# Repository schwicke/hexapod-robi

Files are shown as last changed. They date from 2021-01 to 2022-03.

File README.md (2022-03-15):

# A hexapod robot
The aim of this little project is the creation of a fully self-designed and 3d printed hexapod robot. Basic features:

* 6 legs with 3 Dynamixel motors each
* Controls and feedback through Raspberry-Pi
* Plastic parts self-designed and 3d printed
* Modular design
* Battery or cable driven
* Sensors:
    * pressure sensors in the feeds
    * ultrasonic sensors
    * gyroscopic sensor

The longer term goal is to equip this robot with various additional sensors, giving feedback about the environment and orientation of the robot.

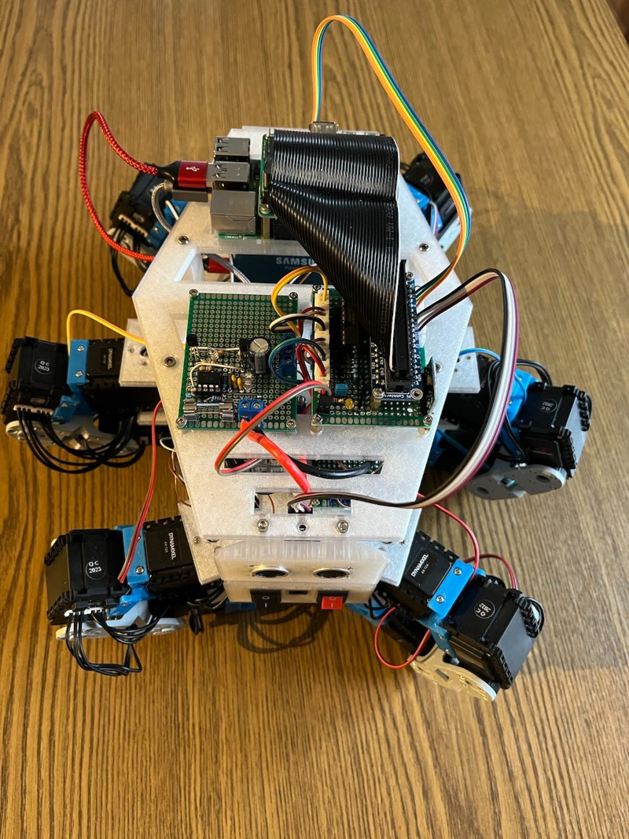
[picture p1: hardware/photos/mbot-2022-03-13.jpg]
Latest robot


## Hardware
A description of the hardware can be found in in the [hardware folder](hardware/README.md).

## Software
The (still PoC level) software is available [here](software/README.md).

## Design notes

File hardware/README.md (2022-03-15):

# Hardware parts
## 3d-printed parts
OpenScad has been used to design the 3d printed parts for this robot. Source files are in the scad folder. These may change at any time and might not work as expected.

The stl folder contains the latest released versions of the plastic parts in STL format, which can be used with your favorite slicer. The intention is to keep them more stable than the source OpenScad files above.

## Required parts list for the robot
Plastic parts: Most up-to-date are the source files for OpenSCAD.

### Legs
* ./legs/joint_30_degrees.scad
* ./legs/leg_connector_boxes_side.scad
* ./legs/sensorunit_bottom.scad
* ./legs/sensorunit_middle.scad
* ./legs/sensorunit_top.scad
* ./legs/leg_connector_boxes.scad

### Body
The body part has 3 different layers, which are:

* ./body/bodybottom.scad
* ./body/bodymiddle.scad
* ./body/bodytop.scad

These are connected using the mount parts

* ./body/mount2.scad
* ./body/mount.scad

The lowest layer hosts the connectors for the motors. For each motor connector, an appropriate connector box is needed:
* ./body/connector_boxes.scad

Finally the body sides are moduler. Currently existing are:
* ./body/side_sensor.scad for the ultrasonic sensors
* ./body/side_power.scad  contains holes for switches
* ./body/side_battery.scad contains holes for the battery connectors

## Electronics:

* 18 Dynamixel AX-12A kits (we need the screws and plastic parts available in these kits as well)
* 1x Raspberry-pi 4b
* 1x Strompi board (Joy-IT)
* 1x Robotis U2D2 board and power distributior
* 2x HC-SR04 Ultrosonic sensors
* 1x MPU6050 sensor
* ADC0838 IC
* LiPo battery, cables and connectors and suitable charger
* 512GB external SSD disk
* 1x voltage converter 12V -> 5V 3A, see circuit diagram
* 1x voltage control board, see circuit diagram below
* 1x ADC board, see circuit diagram below
* 6x RP-C10-ST pressure sensores for the legs

Other parts and materials

* 15x Molex P3 plugs
* 10x 10cm p3 cables from Robotis
* perfboard, cutable into pieces
* 2 small USB cables
* cables, crimp tool, and 4 and 2 pin plugs are needed to connect the sensors

Screws: hexagonal heads, various lengths. These sizes have been used:

* M1.4 (10mm) screws and nuts, at least 8 to fix the HC-SR04 sensors
* M2 (10mm) screws and M2 nuts to mount the legs
* M2.5 (8mm) screws, nuts and washers
* M3 screws and washers

### Motor connectors
Connecting the motors is a bit tricky due to the length of the available cables.
Therefore, in front of roughly each leg there we added additional P3 plugs which help reducing the cable lengths.
The bottom part of the robot has holes forseen for these hubs. To create them, the Molex P3 plugs are soldered on small bits of a PCB perfboard, 3 in pairs of 3 and 2 in pairs of 2 are needed. The pins are to be paired up, like this:

3x motor connector

This picture shows the parts needed to create those boxes:

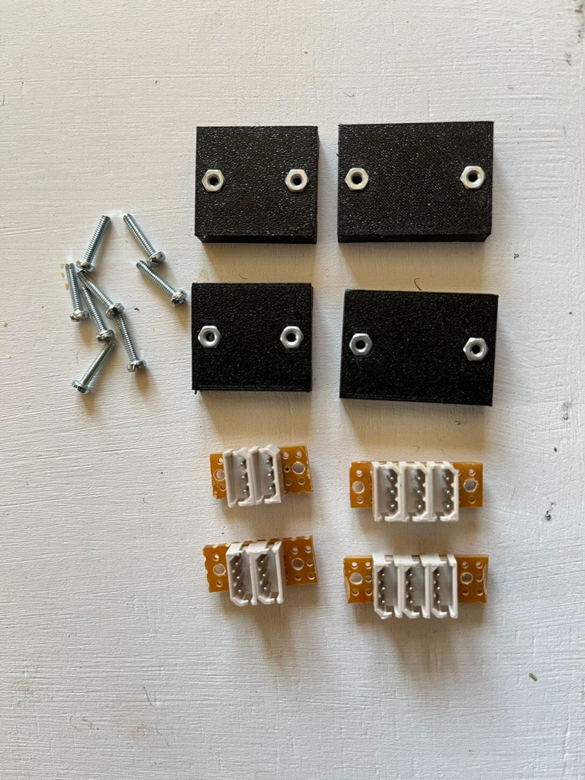
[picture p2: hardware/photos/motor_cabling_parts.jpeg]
Connector parts


The plugs are then inserted into the holes into the bottom part of the robot from below, and fixed with screws with the help of the printed connector boxes. A power distirbution hub seen from below the robot looks like this:
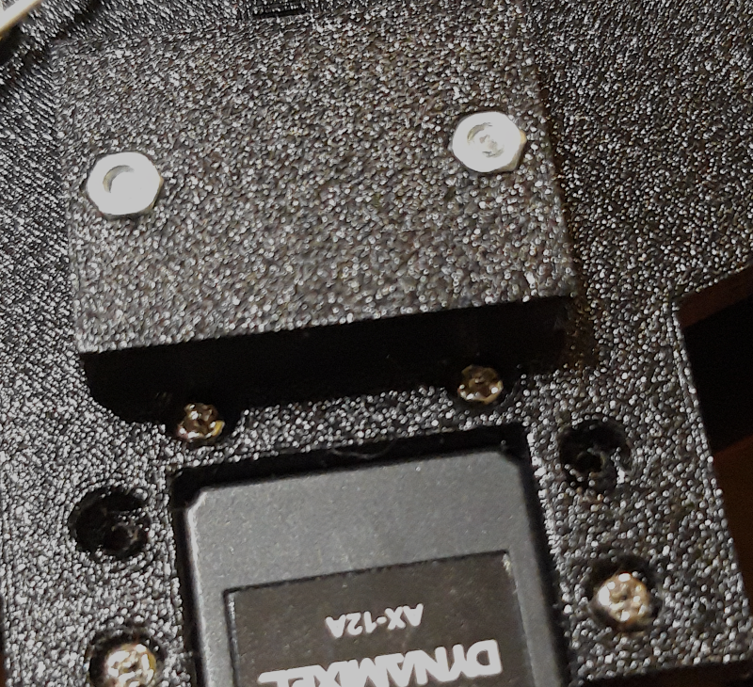
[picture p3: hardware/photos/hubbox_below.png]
Power hub from below


Cabling is done as in the following figure. The still empty plugs are used to connect the legs.

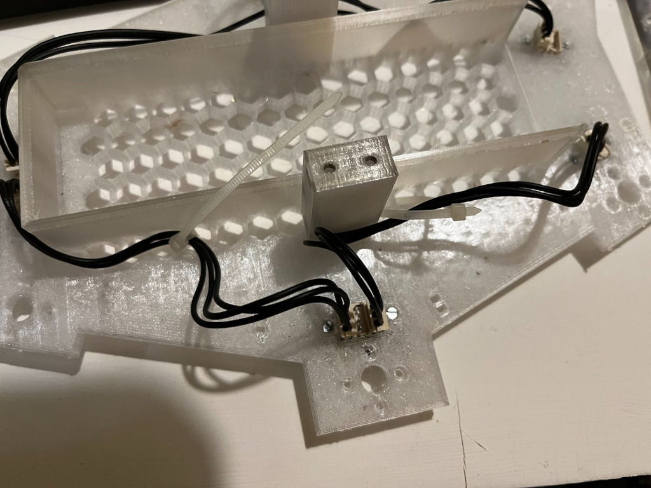
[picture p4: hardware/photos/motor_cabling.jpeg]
Motor cabling


## Voltage converter
A voltage converter is used to provide the required 5V power used by the Raspberry-Pi. The 5V output current is provided via a USB plug, and a short USB 2 to USBC cable is used to connect the two.

Circuits used

The converter is used as power supply for the sensors mainly, to offload the StromPi. As it may not be strictly needed it is possible that it will be dropped in the future.

For the voltage converter is built on a PCB perfboard with dimensions 40x60mm. The regulator IC needs an sufficiently sized heat sink.Using a voltage converter has the advantage that a single power supply of 12V can be used to power the hole robot. In a later version, this may be replaced by a 11.2V Lithium Polymere battery.

Here's a close-up image of how it looks like in reality:
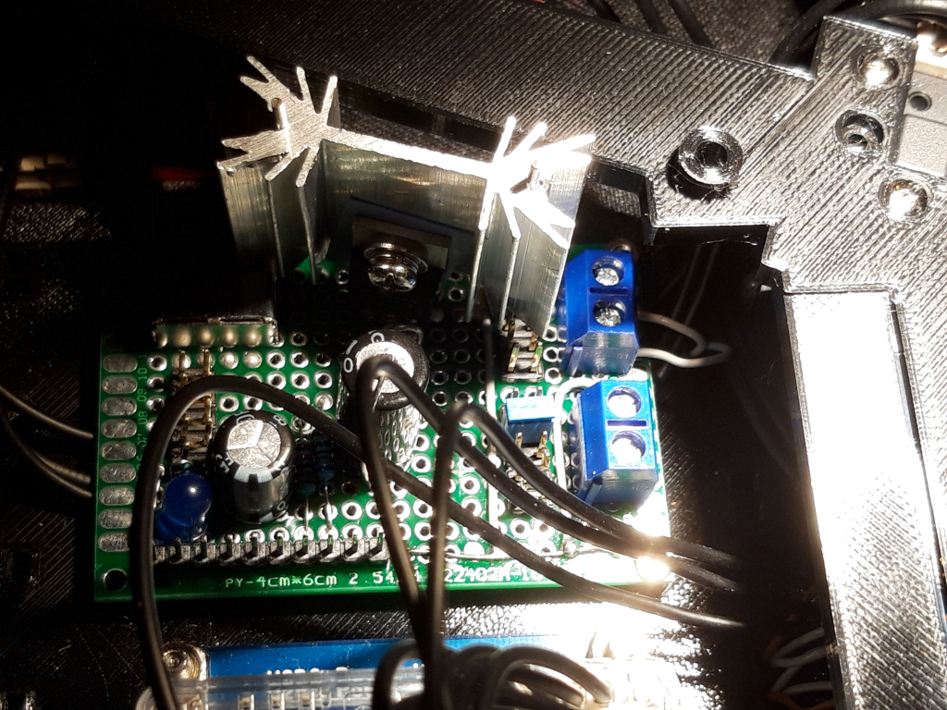
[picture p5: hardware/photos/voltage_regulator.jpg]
Power converter with heat sink


## Voltage controller
The voltage controller is needed to have some control over the status of the battery. It has 2 LEDs, and if the voltage drops too low, a red light will indicate that it is time to recharge the battery.

Circuits used

## ADC board
The ADC board uses an ADC0838 chip to digitize the signals from the pressure sensors in the feets of the robot.

Circuits used

## Layers

### Lowest layer
The first layer takes the motor cabling, as described above, and the battery. The battery should be fixed so that it cannot move or slip out of the robot. A piece of hook-and-loop tape can be used to accomplish this.

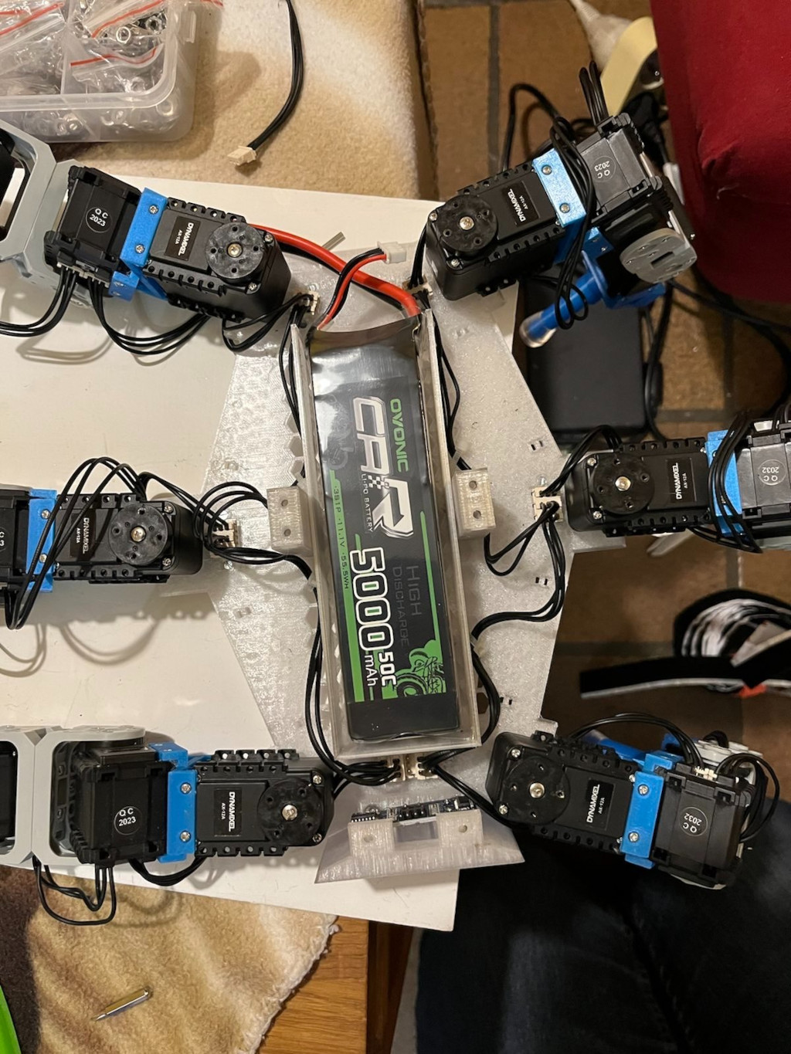
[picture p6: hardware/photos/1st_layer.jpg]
First layer


### Second layer
The second layer takes the SSD disk for the Raspberry-pi, the U2D2 board and optionally the 5V power converter.

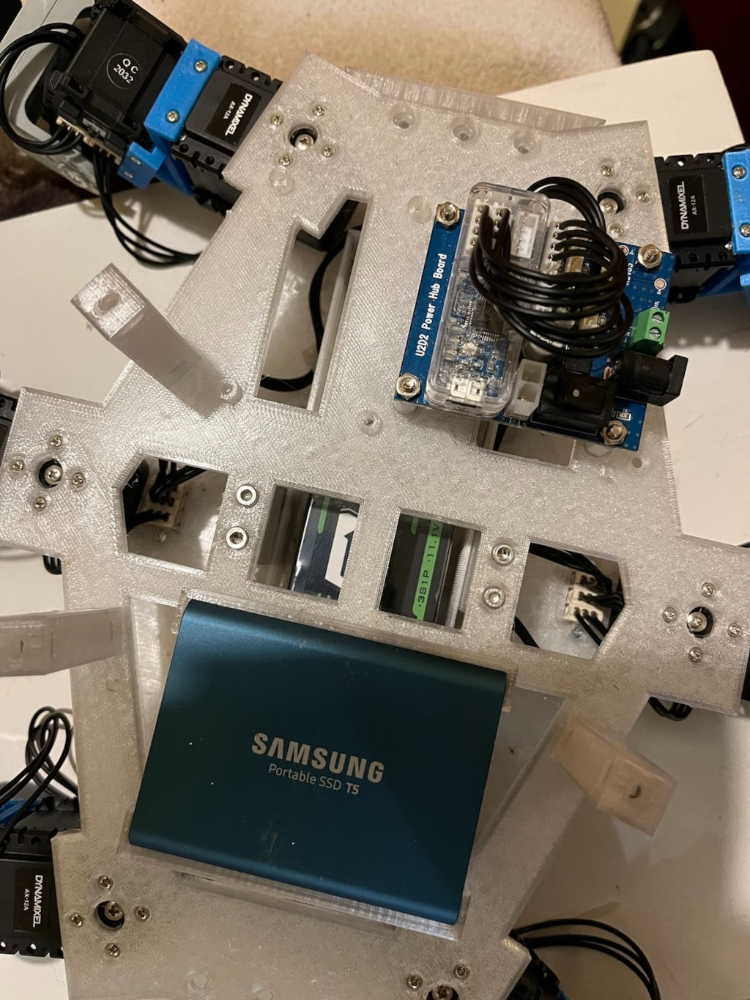
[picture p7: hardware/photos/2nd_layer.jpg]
Second layer


### Top layer
The top layer takes the electronics for the sensors, the Raspberry-Pi, and the power control board.

Third layer

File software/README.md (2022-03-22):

# Software
The software found in this repository is at a PoC level.
## Sensors
This directory contains a library and some tests to read out the robots sensors

## Python
In this folder, you can find some basic Python scripts for motor control
### scan.py
This tool simply scans the bus and returns the ids of the motors it found. There should be 3x6 so 18 of them.
### zero_position.py
This tool simply sets all motors to their zero position. In effect, the robot will stand up.
### walk.py
The walk.py script is a bit more complex. It implements some logic which allows the robot to move a few steps forward and backward.

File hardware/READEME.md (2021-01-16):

# Hardware bits
## 3d-printed parts
OpenScad has been used to design the 3d printed parts for this robot. Source files are in the scad folder. These may change at any time and might not work as expected.

The stl folder contains the latest released versions of the plastic parts in STL format, which can be used with your favorite slicer. The intention is to keep them more stable than the source OpenScad files above.

## Required parts list
Plastic parts:

* 6 legs (6x leg.stl)
* 1x bodybottom.stl
* 1x bodytop.stl
* 5x connector_boxes.stl
* 1x side_buttons.stl
* 1x side_power.stl

Other parts and materials
* 18 Dynamixel AX-12A kits (we need the screws and plastic parts available in these kits as well)
* 1x Robotis U2D2 board
* 1x Raspberry-Pi 4 with 16GB or 32GB SSD card
* 13x Molex P3 plugs
* 10x 10cm p3 cables from Robotis
* perfboard, cutable into pieces

Screws:
* M2 (10mm) screws and M2 nuts to mount the legs
* M2.5 (8mm) screws, nuts and washers
* M3 screws and washers

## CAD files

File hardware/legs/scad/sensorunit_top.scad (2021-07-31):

raster=2.54;
dist = 4.5*raster;

module screwhole_mX(d, height, fact){
   headlength = 0.6*d/2+0.1;
   translate([0,2,0]){
     rotate([90, 0, 0]){
       translate([0, 0, headlength/2]){
         translate([0, 0, height/2])
         cylinder(h=height, r=d/2+0.1, center=true, $fn=50);
         cylinder(h=10*fact*headlength, r=d+0.1, center=true, $fn=50);
       }
     }
   }
}

module nuthole_mX(d){
   s = (d==2) ? 4: (d==2.5)? 5: (d==3) ? 5.5: 0.0;
   if (s==0){
     echo ("Nut size not supported");
   }
   echo(s);
   e = s/sin(60.0);
   height = 40;
   headlength = 0.6*d/2+0.1;
   translate([0, 0, -5*headlength]){
     translate([0, 0, height/2])cylinder(h=height, r=d/2+0.1, center=true, $fn=50);
     cylinder(h=10*headlength, d=e+0.1, center=true, $fn=6);
   }
}

module baseelement(){
     difference(){
       union(){
         difference(){
         translate([0, 0, -4])cube([38, 25, 9], center=true);
         cube([32+0.2, 50, 9], center=true);
         };
       }
       translate([-19, -8, -2])rotate([0,0,90])screwhole_mX(2, 10, 1.0);
       translate([-19,  8, -2])rotate([0,0,90])screwhole_mX(2, 10, 1.0);
       translate([19, -8, -2])rotate([0,0,-90])screwhole_mX(2, 10, 1.0);
       translate([19,  8, -2])rotate([0,0,-90])screwhole_mX(2, 10, 1.0);
  }
}
z=50;
rad=6;
fn=150;
module leg(){
     cylinder(h=z, r=rad, center=false, $fn=fn);
     sphere(r=rad, $fn=fn);
}

//translate([0,0,-z])leg();
//cylinder(h=4, r=rad+1, center=true, $fn=fn);
//sphere(r=rad-2, $fn=fn);
thickness=3;


module tiltedthing(){
     union(){
          translate([0,-5,10])rotate([30,0,0])baseelement();
          translate([0,-0.9,-3])cube([38,22,3], center=true);
          translate([0,8.55,3])cube([38,3,12], center=true);
     }
}

difference(){
     tiltedthing();
     translate([-rad-5,0,2.5])rotate([90,0,0])screwhole_mX(2, 20, 2.0);
     translate([+rad+5,0,2.5])rotate([90,0,0])screwhole_mX(2, 20, 2.0);
     rotate([0,0,180])translate([0,0,-4.6])cylinder(r=rad+1.0,h=1.5,center=true,$fn=fn);
     rotate([0,0,180])translate([0,0,-3.8])cylinder(r=5.1,h=1.1, center=true, $fn=fn);
     rotate([0,0,180])translate([0,-rad,-4.1])cube([7,12,1.1], center=true);
     translate([-dist,8.5,2])rotate([-90,0,0])nuthole_mX(2);
     translate([+dist,8.5,2])rotate([-90,0,0])nuthole_mX(2);
     
}

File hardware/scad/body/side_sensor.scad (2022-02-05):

//
// This file is part of the hexapod-robi distribution (https://github.com/schwicke/hexapod-robi).
// Copyright (c) 2021 Ulrich Schwickerath
//
// This program is free software: you can redistribute it and/or modify
// it under the terms of the GNU General Public License as published by
// the Free Software Foundation, version 3.
//
// This program is distributed in the hope that it will be useful, but
// WITHOUT ANY WARRANTY; without even the implied warranty of
// MERCHANTABILITY or FITNESS FOR A PARTICULAR PURPOSE. See the GNU
// General Public License for more details.
//
// You should have received a copy of the GNU General Public License
// along with this program. If not, see <http://www.gnu.org/licenses/>.
//
// This is a little plastic bit which is intended to get the holes for the connectors
// at the right position. It's not part of the robot itself, but useful for building it.
//
include <../lib/globals.scad>
include <../lib/nuts_and_screws.scad>
include <../lib/sideparts.scad>

translate([0, 5, 0]){
  difference(){
    union(){
      translate([ screwdist_x/2, -1.5, -screwdist_y/2])rotate([90., 0., 0.])cylinder(h=3, d=4, center=true);
      translate([ screwdist_x/2, -1.5,  screwdist_y/2])rotate([90., 0., 0.])cylinder(h=3, d=4, center=true);
      translate([-screwdist_x/2, -1.5,  screwdist_y/2])rotate([90., 0., 0.])cylinder(h=3, d=4, center=true);
      translate([-screwdist_x/2, -1.5, -screwdist_y/2])rotate([90., 0., 0.])cylinder(h=3, d=4, center=true);
      difference(){
        sidepart();
        // HC SR04 sensor
        translate([ halfdist, 0, 0]) rotate([90, 0, 0]) cylinder(h=50, d=diameter, center=true);
        translate([-halfdist, 0, 0]) rotate([90, 0, 0]) cylinder(h=50, d=diameter, center=true);
        translate([0, -7, 0])cube([xsize+0.1, 12, ysize+0.2], center=true);
      }
    }
    translate([ screwdist_x/2, 0,  screwdist_y/2])rotate([-90., 0., 0.])my_screwhole_mX(1.6);
    translate([-screwdist_x/2, 0,  screwdist_y/2])rotate([-90., 0., 0.])my_screwhole_mX(1.6);
    translate([ screwdist_x/2, 0, -screwdist_y/2])rotate([-90., 0., 0.])my_screwhole_mX(1.6);
    translate([-screwdist_x/2, 0, -screwdist_y/2])rotate([-90., 0., 0.])my_screwhole_mX(1.6);
  }
}

translate([0, -5, hight/2-thickness_top/2]){
     difference(){
          rotate([0, 180, 0]) cube([45, 10, thickness_top], center=true);
          translate([ 16, 0, 0]) nuthole_mX(3);
          translate([-16, 0, 0]) nuthole_mX(3);
          translate([0, -0, 10])cube([15, 15, 30], center=true);
     }
}

translate([0, -5, -hight/2+thickness_bottom/2]){
     difference(){
          cube([45, 10, thickness_bottom], center=true);
          translate([  0, 0, 0])rotate([ 180.0 ,0.0 ,0.0 ])nuthole_mX(3);
          translate([ 16, 0, 0])rotate([ 180.0 ,0.0 ,0.0 ])nuthole_mX(3);
          translate([-16, 0, 0])rotate([ 180.0 ,0.0 ,0.0 ])nuthole_mX(3);
     }
}

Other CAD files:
hardware/scad/legs/joint_30_degrees.scad
hardware/scad/legs/leg_connector_boxes.scad
hardware/scad/body/bodybottom.scad
hardware/scad/body/bodymiddle.scad
hardware/scad/body/bodytop.scad
hardware/scad/body/connector_boxes.scad
hardware/scad/body/mount.scad
hardware/scad/body/mount2.scad
hardware/scad/body/side_battery.scad
hardware/scad/body/side_buttons.scad
hardware/scad/body/side_power.scad
hardware/scad/legs/leg_connector_boxes_side.scad
hardware/scad/legs/sensorunit_bottom.scad
hardware/scad/legs/sensorunit_middle.scad
hardware/scad/legs/sensorunit_top.scad

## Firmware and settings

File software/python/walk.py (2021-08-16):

#!/usr/bin/python3
#
# This file is part of the hexapod-robi distribution (https://github.com/schwicke/hexapod-robi).
# Copyright (c) 2021 Ulrich Schwickerath
#
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
""" PoC move primitives """
import sys
import time
#pylint: disable=no-member
from pypot import dynamixel

ALL_MOTORS = [1, 2, 3, 4, 5, 6, 7, 8, 9, 10, 11, 12, 13, 14, 15, 16, 17, 18]
PORT = dynamixel.find_port(ALL_MOTORS)
MOTOR = dynamixel.io.io.DxlIO(PORT, use_sync_read=False)

#print(m.get_angle_limit(ALL_MOTORS))
#print(m.get_control_mode(ALL_MOTORS))
#print(m.get_firmware(ALL_MOTORS))
#print(m.get_present_temperature(ALL_MOTORS))
print(MOTOR.get_present_speed(ALL_MOTORS))

LEG_MOTOR_SPEED = [50, 50, 50]
LEG_GROUPS = [[1, 3, 5], [2, 4, 6]]

# define positions
LEG_ZERO_POS = [0, 0, 0]
LEG_UP_POS = [None, 80, 80]
LEG_DOWN_POS = [None, 0, 0]
LEG_FORWARD_POS = [0, None, None]
LEG_BACKWARD_POS = [-30, None, None]
LEG_SIT_POS = [0, -55, 50]

def _define_motor_hash(legs, positions):
    """ legs: list of legs, position: list of 3 values  """
    res_hash = {}
    for leg in legs:
        for index in range(3):
            mindex = 3*(leg-1)+index + 1
            if positions[index] is not None:
                if mindex in [10, 13, 16] and index == 0:
                    res_hash[mindex] = -positions[index]
                else:
                    res_hash[mindex] = positions[index]
    return res_hash

LEG_GROUPS_SPEED = [_define_motor_hash(LEG_GROUPS[0], LEG_MOTOR_SPEED),
                    _define_motor_hash(LEG_GROUPS[1], LEG_MOTOR_SPEED)]
LEG_GROUPS_ZERO = [_define_motor_hash(LEG_GROUPS[0], LEG_ZERO_POS),
                   _define_motor_hash(LEG_GROUPS[1], LEG_ZERO_POS)]
LEG_GROUPS_UP = [_define_motor_hash(LEG_GROUPS[0], LEG_UP_POS),
                 _define_motor_hash(LEG_GROUPS[1], LEG_UP_POS)]
LEG_GROUPS_DOWN = [_define_motor_hash(LEG_GROUPS[0], LEG_DOWN_POS),
                   _define_motor_hash(LEG_GROUPS[1], LEG_DOWN_POS)]
LEG_GROUPS_FORWARD = [_define_motor_hash(LEG_GROUPS[0], LEG_FORWARD_POS),
                      _define_motor_hash(LEG_GROUPS[1], LEG_FORWARD_POS)]
LEG_GROUPS_BACKWARD = [_define_motor_hash(LEG_GROUPS[0], LEG_BACKWARD_POS),
                       _define_motor_hash(LEG_GROUPS[1], LEG_BACKWARD_POS)]
LEG_GROUPS_SIT = [_define_motor_hash(LEG_GROUPS[0], LEG_SIT_POS),
                  _define_motor_hash(LEG_GROUPS[1], LEG_SIT_POS)]

def zero():
    """ set all MOTORS to zero """
    MOTOR.set_goal_position(LEG_GROUPS_ZERO[0])
    MOTOR.set_goal_position(LEG_GROUPS_ZERO[1])

def set_speed(speed=50):
    """ set the motor speed for all groups """
    leg_groups_speed = [_define_motor_hash(LEG_GROUPS[0], [speed, speed, speed]),
                        _define_motor_hash(LEG_GROUPS[1], [speed, speed, speed])]
    MOTOR.set_moving_speed(leg_groups_speed[0])
    MOTOR.set_moving_speed(leg_groups_speed[1])

def walk_forward(steps, delay=0.5, speed=50):
    """ walk forward by the defined number of steps """
    set_speed(speed)
    zero()
    for i in range(steps):
        print("Step forward number: %d", i)
        for group in range(2):
            MOTOR.set_goal_position(LEG_GROUPS_UP[group])
            time.sleep(delay)
            MOTOR.set_goal_position(LEG_GROUPS_BACKWARD[1-group])
            time.sleep(delay)
            MOTOR.set_goal_position(LEG_GROUPS_FORWARD[group])
            time.sleep(delay)
            MOTOR.set_goal_position(LEG_GROUPS_DOWN[group])
            time.sleep(delay)

def walk_backward(steps, delay=0.5, speed=50):#
    """ walk backward by the defined number of steps """
    set_speed(speed)
    zero()
    for i in range(steps):
        print("Step backward number: %d", i)
        for group in range(2):
            MOTOR.set_goal_position(LEG_GROUPS_UP[group])
            time.sleep(delay)
            MOTOR.set_goal_position(LEG_GROUPS_FORWARD[1-group])
            time.sleep(delay)
            MOTOR.set_goal_position(LEG_GROUPS_BACKWARD[group])
            time.sleep(delay)
            MOTOR.set_goal_position(LEG_GROUPS_DOWN[group])
            time.sleep(delay)

def main():
    """ main entry point """
    set_speed(80)
    zero()
    steps = 5
    wait = 0.15
    speed = 130
    time.sleep(1)
    walk_backward(steps, wait, speed)
    #walk_forward(steps,  wait, speed)
    set_speed(30)
    MOTOR.set_goal_position(LEG_GROUPS_SIT[1])
    MOTOR.set_goal_position(LEG_GROUPS_SIT[0])
    #zero()

if __name__ == '__main__':
    sys.exit(main())

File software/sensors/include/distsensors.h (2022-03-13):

#ifndef HCSR04_H
#define HCSR04_H
#include "common.h"
/* define trigger and echo pins for the two sensors */

#define trig1Pin 19
#define echo1Pin 26
struct gpiod_line *trig1Line;
struct gpiod_line *echo1Line;

#define trig2Pin 13
#define echo2Pin 6

struct gpiod_line *trig2Line;
struct gpiod_line *echo2Line;

#endif

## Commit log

2021-01-08 add initial 3d parts
    [bodybottom.scad, bodytop.scad, bodytop.stl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]
2021-01-13 remove duplicate code
    [bodybottom.scad, bodytop.scad, common.scad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]
2021-01-16 add License and README for the hardware
    [bodybottom.scad, bodytop.scad, bodytop.stl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]
2021-01-17 remove more duplicate code
    [side_buttons.scad, side_closed.scad, side_power.scad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]
2021-01-17 add license and simplify
    [bodybottom.scad, bodytop.scad, common.scad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]
2021-01-17 reshuffle code and remove left-overs
    [bodybottom.scad, bodytop.scad, common.scad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]
2021-01-17 pass on parameters
    [common.scad]
2021-02-17 switch to svg file
2021-02-17 correct spacers
    [bodybottom.scad]
2021-02-17 add holes for the hubs
    [common.scad]
2021-02-18 update bottom stl part with holes for hubs
2021-02-18 add picture to explain the power hubs better
2021-02-19 move raspi by 5mm and increase size of hole to access the SD card
    [bodybottom.scad, common.scad]
2021-07-31 prototyping new version
    [bodybottom.scad, bodymiddle.scad, bodytop.scad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]
2021-07-31 add connector boxes which are stil needed
    [connector_boxes.scad]
2021-07-31 remove obsolete file
    [spinnenbein_v0.2.scad]
2021-08-01 consolidate and cleanup the code for the legs
    [bodybottom.scad, bodymiddle.scad, connector_boxes.scad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]
2021-08-01 reshuffle the code and add headers where missing
    [bodybottom.scad, bodymiddle.scad, connector_boxes.scad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]
2021-08-01 add stl files
    [bodytop.stl, connector_boxes.stl, leg.stl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]
2021-08-01 add leg STL files
    [joint_30_degrees.stl, leg_connector_boxes.stl, sensorunit_bottom.stl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]
2021-08-15 more space for the connectors
2021-08-15 improve cabling and allow to exchange battery
    [bodybottom.scad]
2021-08-15 correct the pi
    [bodymiddle.scad]
2021-08-15 correct hole distance
    [side_power.scad]
2021-08-15 add box for 5 connectors
    [connector_boxes.scad]
2021-08-16 adjust hight
    [mount.scad]
2021-08-16 update sample walk.py for the new model and pylint it
2021-08-16 shorten the legs so that they do not touch each other when sitting
    [sensorunit_bottom.scad]
2021-08-16 suggest sensors and update parts lists
2021-08-31 re-iterate on the body layers
    [bodymiddle.scad]
2021-09-03 turn the u2d2 board by 90 degrees
    [bodymiddle.scad]
2021-09-10 add pad sensor electronics and readout tests
2021-09-25 draft box with 90 degrees connector
    [leg_connector_boxes_side.scad]
2021-09-25 add leg_connector_boxes_side.stl
    [leg_connector_boxes_side.stl]
2021-12-23 rescale connectors
    [leg_connector_boxes_side.scad]
2022-01-06 adjust new boxes
    [leg_connector_boxes_side.scad, leg_connector_boxes_side.stl]
2022-01-08 partial roll back
    [bodymiddle.scad]
2022-01-08 move pi up and add SSD in middle layer
    [bodymiddle.scad, bodytop.scad]
2022-01-12 add bit to mount the 3rd layer on the 2nd
    [mount2.scad]
2022-01-12 add M3 screw holes to mount 2nd and 3rd layer on top of each other
    [bodymiddle.scad, bodytop.scad]
2022-01-16 correct whole and cleanup obsolete battery stuff
    [bodymiddle.scad]
2022-01-17 allow for a bit more space for the SSD
    [bodymiddle.scad]
2022-01-18 change screw type at the sides
    [bodytop.scad]
2022-01-22 add space for heads for pi screws
    [bodytop.scad]
2022-01-22 HCSR04 sensor holder
    [side_power.scad, side_sensor.scad]
2022-01-23 change to screwholes
    [side_sensor.scad]
2022-01-24 cut off sides and improve fitting for sensor
    [side_sensor.scad]
2022-01-25 tune the mounts
    [mount2.scad]
2022-01-28 increase the size of the connector holes a bit
    [bodybottom.scad]
2022-01-30 increase switch hole size and correct plug position
    [side_power.scad]
2022-02-05 add more options to screw things together
    [side_power.scad, side_sensor.scad]
2022-02-17 prototype comparator
2022-03-07 recenter the figure
    [side_battery.scad]
2022-03-07 add holes to connect ultrasonics and changes screwholes
    [bodytop.scad]
2022-03-12 correct decoding of foot sensors
    [adc0838.c]
2022-03-13 add distance sensors
2022-03-13 Update documentation and remove stale STL files
    [bodybottom.stl, joint_30_degrees.stl, leg_connector_boxes.stl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]
2022-03-13 add also voltage regulater picture
2022-03-22 add a single tool reading out all sensors
